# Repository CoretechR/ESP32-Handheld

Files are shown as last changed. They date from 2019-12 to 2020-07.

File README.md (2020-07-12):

# ESP32-Handheld

My image

Tested with Arduino for ESP32 Core 1.0.4

The lastes firmware needs the modified Adafruit SharpMem library. This library includes a hugely faster screen clearing function and hardware SPI.







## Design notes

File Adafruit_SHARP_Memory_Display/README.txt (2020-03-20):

This is an Arduino library for our Monochrome SHARP Memory Displays

  Pick one up today in the adafruit shop!
  ------> http://www.adafruit.com/products/1393

These displays use SPI to communicate, 3 pins are required to  
interface

To install this library, check out our detailed library install tutorial:
http://learn.adafruit.com/adafruit-all-about-arduino-libraries-install-use

Also requires the Adafruit GFX library, install the same way
https://github.com/adafruit/Adafruit-GFX-Library

Adafruit invests time and resources providing this open source code, 
please support Adafruit and open-source hardware by purchasing 
products from Adafruit!

Written by Limor Fried & Kevin Townsend  for Adafruit Industries.  
BSD license, check license.txt for more information
All text above, and the splash screen must be included in any redistribution

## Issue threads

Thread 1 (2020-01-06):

PJON compatible handheld device

gioblu, 2020-01-06:
Ciao Max, this is not really an issue.
I have really enjoyed your hackaday projects and this efficient handheld device.
Have you ever heard about PJON: https://github.com/gioblu/PJON ?

Would you be interested to work with us on something interesting?
This is my email gioscarab@gmail.com

Sorry for squatting the issues of this project to get in touch with you.

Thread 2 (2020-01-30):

Able to upload Bill Of Materials?

xlfe, 2020-01-30:
What a great project!

Any chance you would be able to upload a BOM please?

CoretechR, 2020-02-07:
Sorry for taking so long but here's the BOM:
[ESP32 Handheld BOM.txt](https://github.com/CoretechR/ESP32-Handheld/files/4172634/ESP32.Handheld.BOM.txt)

xlfe, 2020-02-08:
That's awesome - much appreciated @CoretechR

You wouldn't happen to have Digikey Part Numbers too?

CoretechR, 2020-02-08:
[Digikey Part Numbers.txt](https://github.com/CoretechR/ESP32-Handheld/files/4174643/Digikey.Part.Numbers.txt)
Please double check with the schematic. I already had some of the parts from other sources.

xlfe, 2020-02-09:
@CoretechR that's great - thank you.

Closed 2020-02-09.

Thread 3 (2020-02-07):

comments in code: save 80µA? and pinMode saves 10µA? how?

mahesh2000, 2020-02-07:
hi, the `Memo.ino` file states that two of the lines save 10µA and 80µA. could you point me towards the documentation that has more info about this? thanks!
the lines are:
```
pinMode(0, OUTPUT); // don't change, -10µA???
```

and

```
rtc_gpio_pulldown_dis(ulp_toggle_num); // disable VCOM pulldown (saves 80µA)
```

CoretechR, 2020-02-07:
These are values/improvements I made while monitoring the current with a multimeter.
The 80µA is probably caused by the VCOM being in a high state and the pulldown drawing current.
For the 10µA I have no idea, sorry. I was experimenting and this fix seemed to reduce current draw.

mahesh2000, 2020-02-07:
hi, what is VCOM? i didn't see that name on any of the pins. also, i got it down to 40uA in sleep mode; it's still 4x what ESP32 claims. but still pretty good. i removed several parts (see photos of surgery) the UART chip (scraped the pins off, it was too difficult to remove), "LDO" (if you can call it that), various resistors, transistors, a power inductor, pretty much everything. i left the tantalum capacitor in place as it was between Vcc and GND. and for the test code i used yours and some more:
```
/**
 * Reduce power consumption of the ESP32 during sleep
 *
 * Mahesh Viswanathan, Jan 2020, mahesh@leakspotter.com
 *
 */

// With just sleep code, consumption went down to 7.3mA, far too much.
// After removing the USB voltage regulator, a power inductor, UART. got it down to 40uA!

// probably don't need all these headers
#include "esp_sleep.h"
#include "driver/rtc_io.h"
#include "esp32/ulp.h"
#include "driver/adc.h"
#include "esp_wifi.h"
#include "esp_bt.h"
#include "WiFi.h"
#include <esp_wifi.h>
#include "esp32-hal-bt.h"

// from https://www.savjee.be/2019/12/esp32-tips-to-increase-battery-life/
void goToDeepSleep()
{
  Serial.println("Going to sleep...");
  WiFi.disconnect(true);
  WiFi.mode(WIFI_OFF);
  btStop();

  adc_power_off();
  //esp_wifi_stop();  // this crashes
  esp_bt_controller_disable();

  #define DEEP_SLEEP_TIME 15
  // Configure the timer to wake us up!
  esp_sleep_enable_timer_wakeup(DEEP_SLEEP_TIME * 60L * 1000000L);

  // Go to sleep! Zzzz
  esp_deep_sleep_start();
}
/**
 * Save power. from https://desire.giesecke.tk/index.php/2018/02/15/deep-sleep-needs-wifi-switched-off-for-low-current-consumption/
 * To achieve maximum power saving during deep sleep it is apparently necessary to switch off Bluetooth and WiFi before calling esp_deep_sleep_start();
 */
static void power_things_off() {
  // esp_wifi_stop(); // this causes endless rebooting. why?
  esp_sleep_pd_config(ESP_PD_DOMAIN_RTC_PERIPH, ESP_PD_OPTION_OFF);
  //WiFi.mode( WIFI_MODE_NULL );
  WiFi.mode(WIFI_OFF);
  btStop();
  adc_power_off();

  rtc_gpio_isolate((gpio_num_t) RTCIO_CHANNEL_0_GPIO_NUM);  //    36
  rtc_gpio_isolate((gpio_num_t) RTCIO_CHANNEL_1_GPIO_NUM); //    37
  rtc_gpio_isolate((gpio_num_t) RTCIO_CHANNEL_2_GPIO_NUM); //    38
  rtc_gpio_isolate((gpio_num_t) RTCIO_CHANNEL_3_GPIO_NUM); //    39
  rtc_gpio_isolate((gpio_num_t) RTCIO_CHANNEL_4_GPIO_NUM); //    34
  rtc_gpio_isolate((gpio_num_t) RTCIO_CHANNEL_5_GPIO_NUM); //    35
  rtc_gpio_isolate((gpio_num_t) RTCIO_CHANNEL_6_GPIO_NUM); //    25
  rtc_gpio_isolate((gpio_num_t) RTCIO_CHANNEL_7_GPIO_NUM); //    26
  rtc_gpio_isolate((gpio_num_t) RTCIO_CHANNEL_8_GPIO_NUM); //    33
  rtc_gpio_isolate((gpio_num_t) RTCIO_CHANNEL_9_GPIO_NUM); //    32
  rtc_gpio_isolate((gpio_num_t) RTCIO_CHANNEL_10_GPIO_NUM);  //   4
  rtc_gpio_isolate((gpio_num_t) RTCIO_CHANNEL_11_GPIO_NUM);  //   0
  rtc_gpio_isolate((gpio_num_t) RTCIO_CHANNEL_12_GPIO_NUM);  //   2
  rtc_gpio_isolate((gpio_num_t) RTCIO_CHANNEL_13_GPIO_NUM);  //   15
  rtc_gpio_isolate((gpio_num_t) RTCIO_CHANNEL_14_GPIO_NUM);  //   13
  rtc_gpio_isolate((gpio_num_t) RTCIO_CHANNEL_15_GPIO_NUM);  //   12
  rtc_gpio_isolate((gpio_num_t) RTCIO_CHANNEL_16_GPIO_NUM);  //   14
  rtc_gpio_isolate((gpio_num_t) RTCIO_CHANNEL_17_GPIO_NUM);  //   27

  //void rtc_gpio_force_hold_dis_all();
  rtc_gpio_force_hold_dis_all();

}

void print_wakeup_cause(esp_sleep_wakeup_cause_t cause) {
  Serial.print("Wakeup cause: ");
  if(cause == ESP_SLEEP_WAKEUP_UNDEFINED) Serial.println("ESP_SLEEP_WAKEUP_UNDEFINED"); //normal reset
  else if(cause == ESP_SLEEP_WAKEUP_ALL) Serial.println("ESP_SLEEP_WAKEUP_ALL");
  else if(cause == ESP_SLEEP_WAKEUP_EXT0) Serial.println("ESP_SLEEP_WAKEUP_EXT0");
  else if(cause == ESP_SLEEP_WAKEUP_EXT1) Serial.println("ESP_SLEEP_WAKEUP_EXT1"); //button A&B
  else if(cause == ESP_SLEEP_WAKEUP_TIMER) Serial.println("ESP_SLEEP_WAKEUP_TIMER"); //scheduled timer wakeup
  else if(cause == ESP_SLEEP_WAKEUP_TOUCHPAD) Serial.println("ESP_SLEEP_WAKEUP_TOUCHPAD");
  else if(cause == ESP_SLEEP_WAKEUP_ULP) Serial.println("ESP_SLEEP_WAKEUP_ULP");
  else if(cause == ESP_SLEEP_WAKEUP_GPIO) Serial.println("ESP_SLEEP_WAKEUP_GPIO");
  else if(cause == ESP_SLEEP_WAKEUP_UART) Serial.println("ESP_SLEEP_WAKEUP_UART");
}

/**
 * Entry point
 */
void setup(){
  delay(500); // "Unfortunately, the ESP32 software & hardware is not mature yet. There is a software or hardware bug that appears in both the ESP32 boards I tried when using the deep sleep mode. After a random number of wakes up, the ESP32 goes to sleep and it won’t wake up again. This bug can happen after a couple of wake ups or after 100. It is just random. One simple solution I discovered is to add a small delay of 500ms after waking up and before reading from the RTC memory. This way the project worked fine, but of course, the penalty we pay is reduced battery life, because the chip is in active mode for 500ms more in each wake-up. I think this bug will be resolved in the near future with a new software or hardware fix."
  // from https://www.hackster.io/nickthegreek82/esp32-deep-sleep-tutorial-4398a7

  esp_sleep_wakeup_cause_t cause = esp_sleep_get_wakeup_cause();
  pinMode(0, OUTPUT); // don't change, -10µA???

  Serial.begin(115200);
  delay(100);
  print_wakeup_cause(cause);

  power_things_off();
  goToDeepSleep();
}

void loop(void){
  Serial.println("You should never get here.");
}
```
Original, virgin board:
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

After ravaging -- look at all mess of parts desoldered and/or ripped out with needlenose pliers :-):
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

CoretechR, 2020-02-09:
From the code I can't see any obvious problems. With such a board it might be difficult to reliably measure the current. It would be best to measure directly on the VCC supply of the ESP32. Maybe you can cut a trace there and connect your multimeter. It also can help to set different "suspicious" pins to a low state, for example tx/rx or anything that's connected to other ICs. However 40µA is a pretty good result already.

mahesh2000, 2020-02-09:
yes, 40uA is good enough for me. that's why i'm not cutting out the rest. my multimeter is between my +3.3V and Vcc. the way i read the current is this:

```
3.3V _____/ _________ Vcc
       |          |
       |___ MM ___|

```

Close the switch. start the ESP32. put it into sleep mode. open the switch so the current now goes through the multimeter, which should be at the lowest setting. if you don't do that, the MM won't let enough current through and the ESP32 will not start properly. Once in sleep mode, it consumes very little current and this will give a good result. until the core wakes up again.

CoretechR, 2020-02-09:
Just a tip, you can also put a diode in parallel with the multimeter. The diode will let enough current through during startup and in sleep mode the diode will block nearly all current.
https://electronics.stackexchange.com/questions/340330/measure-wide-range-of-current-800-%c2%b5a-1-5-a/340353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
Oh, and VCOM is just part of the sharp display interface that I used.

mahesh2000, 2020-02-09:
does he mean i should use that circuit and put the MM across the 100 ohm resistor? it's not clear. it looks like an elegant solution.

CoretechR, 2020-02-09:
If you put your multimeter in current mode you only need the diode, the resistor is only a shunt for measuring the current.
```
3.3V ______▷| ________ Vcc Pin
       |          |
       |___ MM ___|

```

mahesh2000, 2020-02-09:
oh, nice!

Closed 2020-02-09.

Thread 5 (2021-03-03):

modify pins

Hausenbourne, 2021-03-03:
Hello friend, your project is really cool. I encountered some problems in the process of doing your project. Your SHARP_ VCOM pin is connected to IO2 pin of esp32, SHARP_ EXTMODE pin is connected to IO4 pin of esp32. Now I want to modify these two pins to connect to other IO ports of esp32. I have checked your code, but I can't find the relevant pin settings.

`#define SHARP_SCK  14`
`#define SHARP_MOSI 13`
`#define SHARP_SS   15`

CoretechR, 2021-03-04:
Hi,
the VCOM pin is toggled with the low power core of the ESP32. You need to look at this file to change the pin but not all pins on the ESP32 are available for it. About the EXTMODE I have no clue. Maybe I forgot to configure it and it works accidentally. It is pulled to ground by the default Arduino pin setting. And in standby there might be a weak pullup. I am not so sure anymore.

Closed 2021-12-29.

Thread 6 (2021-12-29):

Sharp Memory Display ESP32C3 RISC-V Compatibility

dgiampetruzzi, 2021-12-29:
Hi, thank you for this amazing project. I need an information. I would like to use the ESP32C3 to control the Sharp Memory Display. I know I could not use ULP to trigger VCOM (I would use an external RTC for this function). In general, is the library to drive this display compatible with the ESP32C3?
Thank you!

CoretechR, 2021-12-29:
Hi, the underlying library is Adafruit GFX (https://github.com/adafruit/Adafruit-GFX-Library). I have not used a ESP32C3 before so I can't guarantee that it works. But it seems likely as the only necessary peripheral is SPI. The only way to find out is to try it.  :)
Using an RTC for the 1Hz signal is a good idea. Does the ESP32C3 not have a ULP at all?

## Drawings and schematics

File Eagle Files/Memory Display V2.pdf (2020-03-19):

# ESP32 Wroom

FTDI Adapter | LiPo Charger

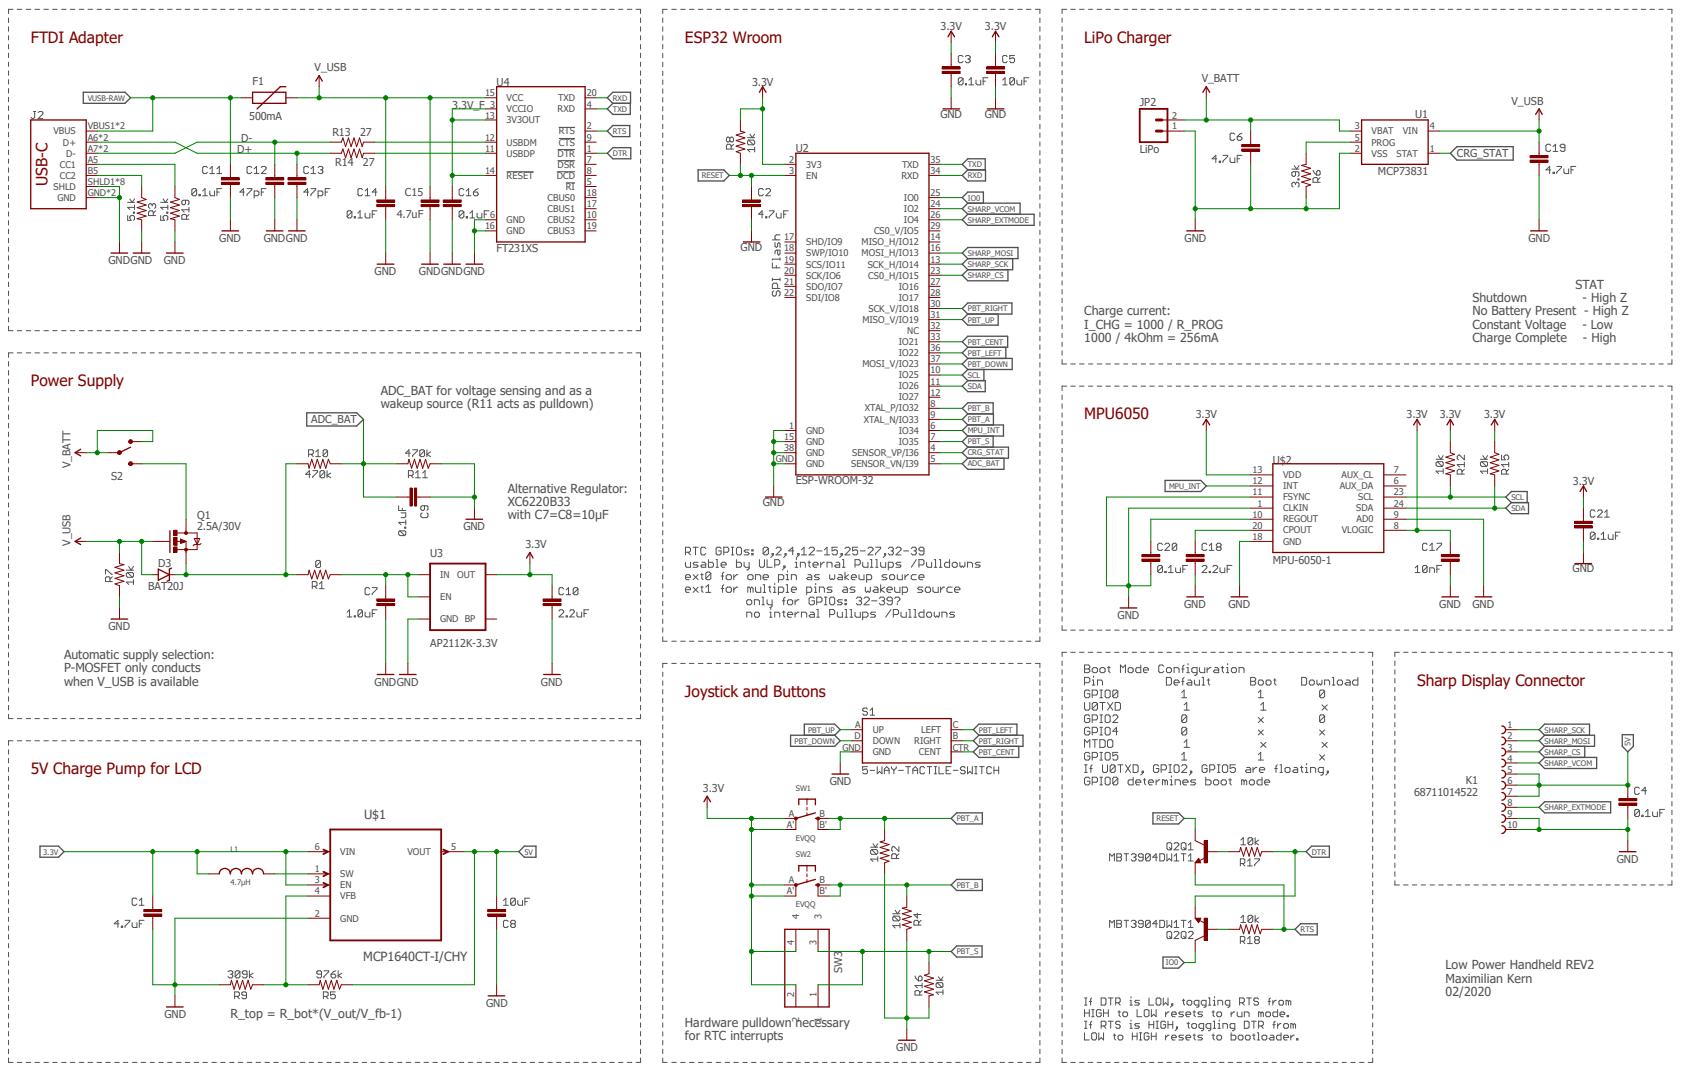
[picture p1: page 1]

No Battery Present - High Z
Constant Voltage - Low
Charge Complete - High

ADC_BAT for voltage sensing and as a
wakeup source (R11 acts as pulldown)

5V Charge Pump for LCD

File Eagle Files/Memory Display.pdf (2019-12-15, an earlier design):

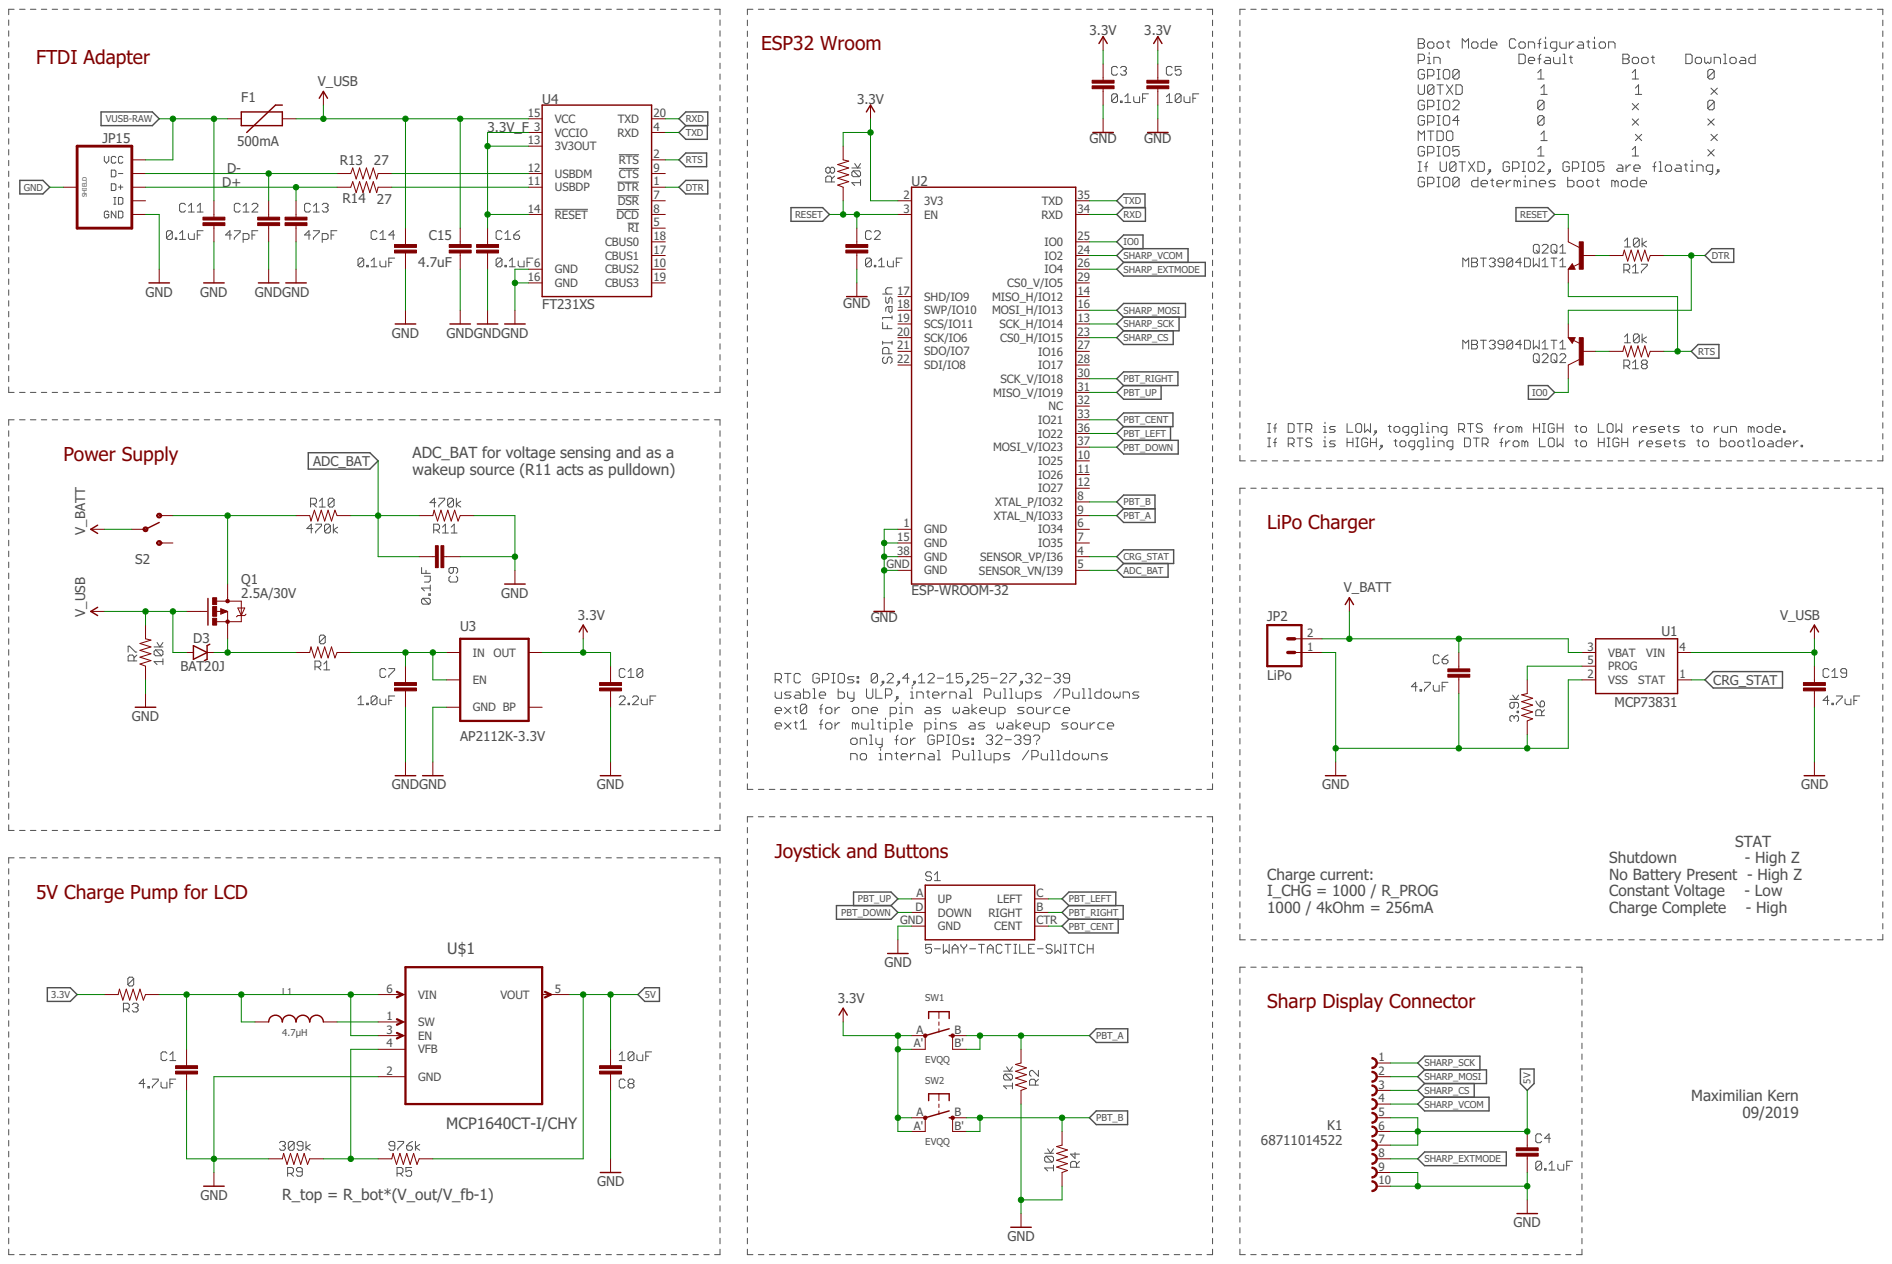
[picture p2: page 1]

ADC_BAT for voltage sensing and as a wakeup source (R11 acts as pulldown)

No Battery Present - High Z

5V Charge Pump for LCD

PBT_UP | PBT_LEFT
PBT_DOWN GND | PBT_RIGHT

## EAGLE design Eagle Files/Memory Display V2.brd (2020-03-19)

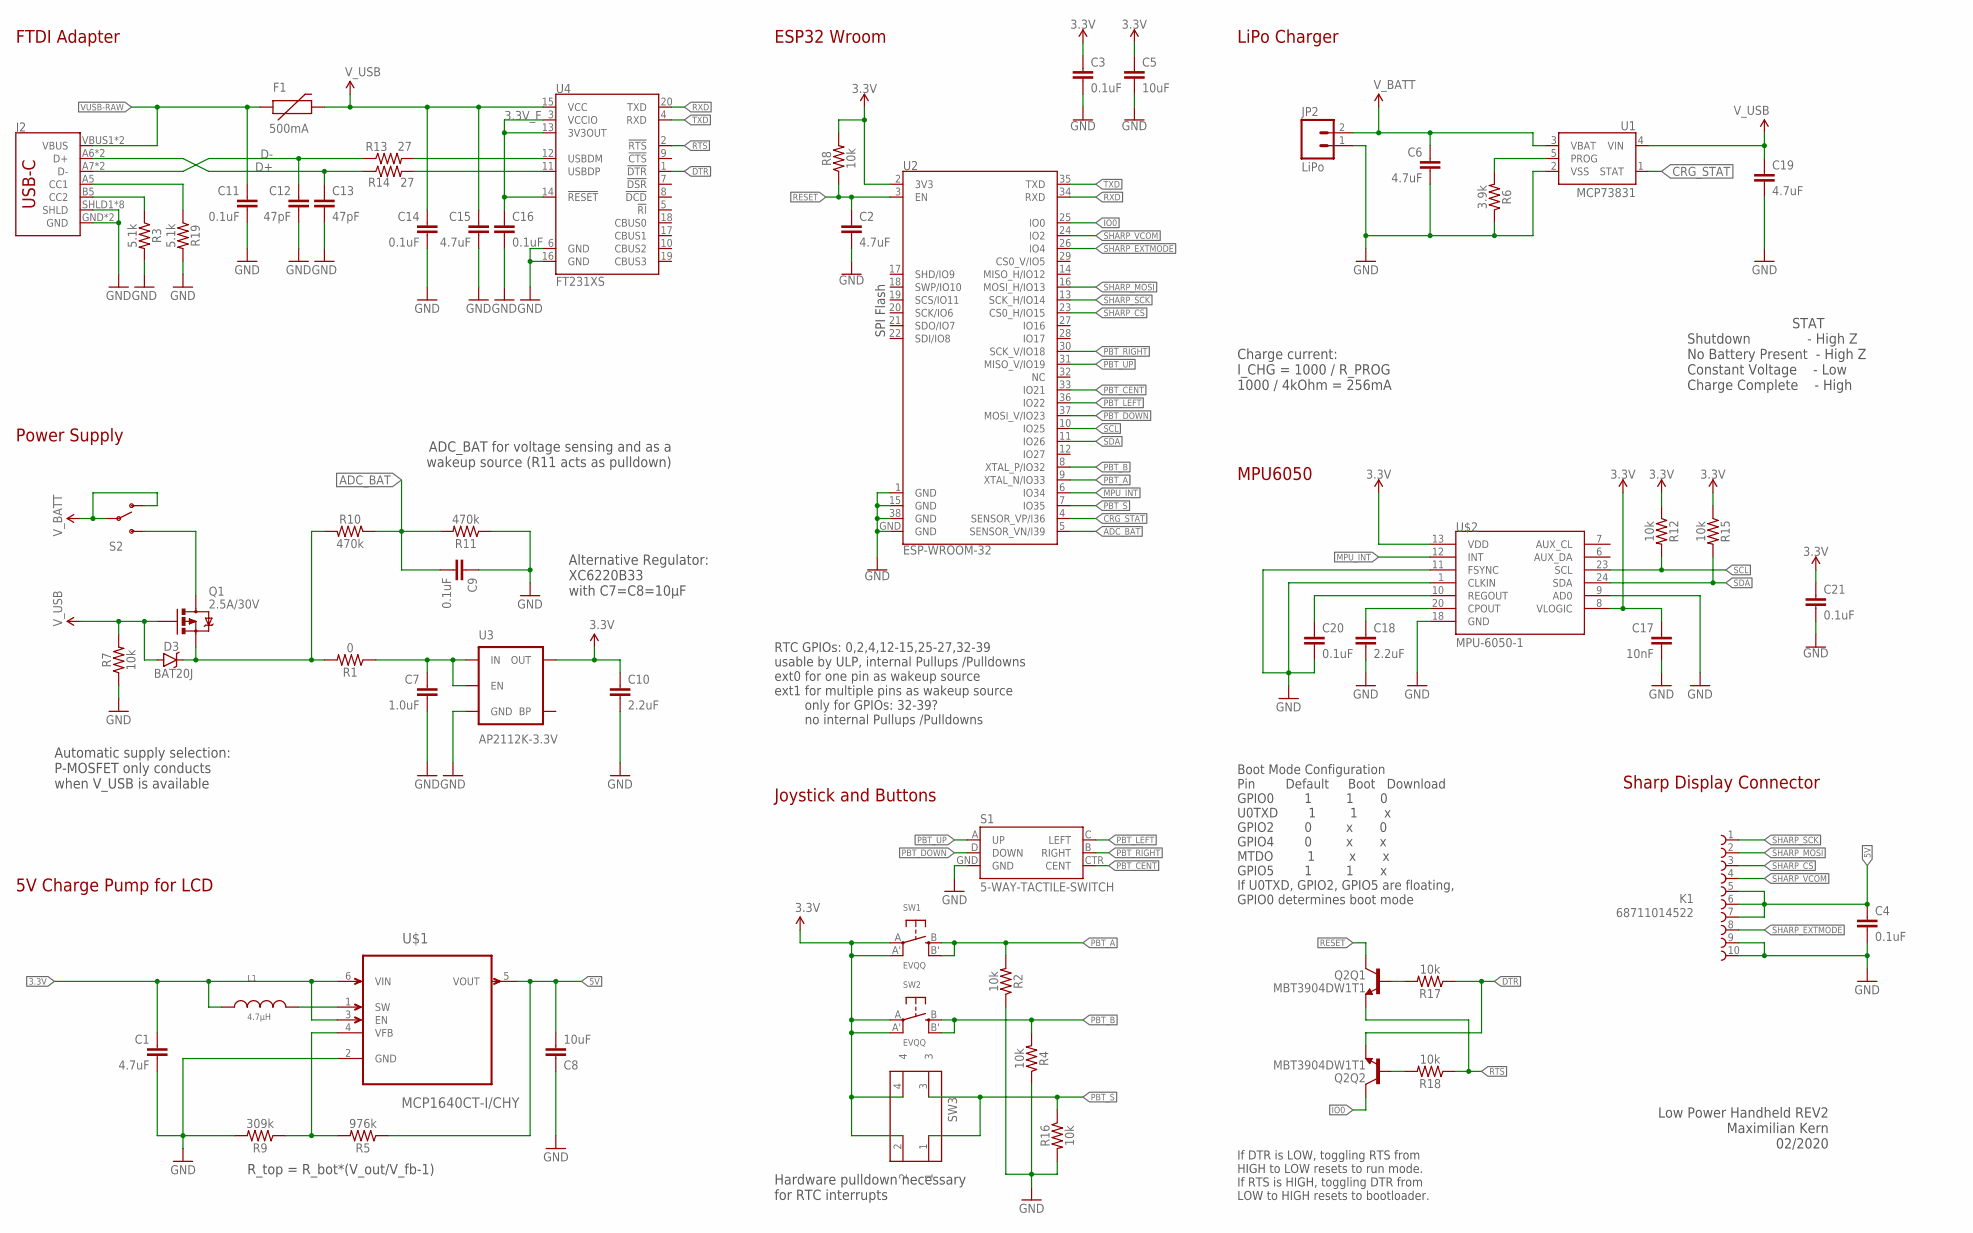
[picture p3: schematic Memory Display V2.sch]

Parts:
C1, C2, C6, C19: 4.7uF; 0603
C3, C4, C9, C11, C14, C16, C20, C21: 0.1uF; 0603
C5, C8: 10uF; 0603
C7: 1.0uF; 0805
C10, C18: 2.2uF; 0805
C12, C13: 47pF; 0603
C15: 4.7uF; 0603-CAP
C17: 10nF; 0603
D3: BAT20J; SOD-323
F1: 500mA; PTC-1206
J2: USB_C16PIN; USB-C-16P
JP2: LiPo; JST-2-PTH
K1: 68711014522
L1: 4.7µH; WE-TPC_2811/2813_OLD
Q1: 2.5A/30V; SOT23-3
Q2: MBT3904DW1T1; SC70-6
R1: 0; 0603
R2, R4, R7, R8, R12, R15, R16, R17, R18: 10k; 0603
R3, R19: 5.1k; 0603
R5: 976k; 0603
R6: 3.9k; 0603
R9: 309k; 0603
R10, R11: 470k; 0603
R13, R14: 27; 0603
S1: 5-WAY-TACTILE-SWITCH; JOYSTICK_MINI
S2: SWITCH-SPDT-SMD-A; SWITCH-SPST-SMD-A
SW1, SW2: EVQQ; EVQ-Q2_SMALLER
SW3: 434331045822
U1: MCP73831; SOT23-5
U2: ESP-WROOM-32
U3: AP2112K-3.3V; SOT23-5
U4: FT231XS; SSOP20_L
U$1: MCP1640CT-I/CHY; SOT95P270X145-6N
U$2: MPU-6050-1; QFN-24-4MM2

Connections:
3.3V: C1.1, C3.1, C5.1, C10.1, C17.1, C21.1, L1.1, R8.2, R12.1, R15.1, SW1.A, SW1.A' (P1), SW2.A, SW2.A' (P1), SW3.2, SW3.4, U2.2 (3V3), U3.5 (OUT), U$1.3 (EN), U$1.6 (VIN), U$2.8 (VLOGIC), U$2.13 (VDD)
3.3V_F: C16.1, U4.3 (VCCIO), U4.13 (3V3OUT), U4.14 (!RESET)
5V: C4.1, C8.2, K1.5, K1.6, K1.7, R5.1, U$1.5 (VOUT)
ADC_BAT: C9.2, R10.1, R11.2, U2.5 (SENSOR_VN/I39)
B_VFB: R5.2, R9.1, U$1.4 (VFB)
CRG_STAT: U1.1 (STAT), U2.4 (SENSOR_VP/I36)
D+: C13.1, J2.A6 (D+), J2.B6 (D+), R14.1
D-: C12.1, J2.A7 (D-), J2.B7 (D-), R13.1
DTR: Q2.1 (E), R17.1, U4.1 (!DTR)
GND: C1.2, C2.2, C3.2, C4.2, C5.2, C6.2, C7.2, C8.1, C9.1, C10.2, C11.2, C12.2, C13.2, C14.2, C15.2, C16.2, C17.2, C18.2, C19.2, C20.2, C21.2, J2.GND, J2.GND2 (GND), J2.SHLD1 (SHLD), J2.SHLD2 (SHLD), J2.SHLD3 (SHLD), J2.SHLD4 (SHLD), J2.SHLD5 (SHLD), J2.SHLD6 (SHLD), J2.SHLD7 (SHLD), J2.SHLD8 (SHLD), JP2.1, K1.9, K1.10, R2.1, R3.2, R4.1, R6.1, R7.1, R9.2, R11.1, R16.2, R19.2, S1.GND, U1.2 (VSS), U2.1 (GND), U2.15 (GND), U2.38 (GND), U2.GND, U3.2 (GND), U4.6 (GND), U4.16 (GND), U$1.2 (GND), U$2.1 (CLKIN), U$2.9 (AD0), U$2.11 (FSYNC), U$2.18 (GND)
IO0: Q2.6 (C), U2.25 (IO0)
MPU_INT: U2.6 (IO34), U$2.12 (INT)
unnamed: L1.2, U$1.1 (SW)
unnamed: C7.1, R1.1, U3.1 (IN), U3.3 (EN)
unnamed: Q1.3 (D), S2.3 (S)
unnamed: D3.C, Q1.2 (S), R1.2, R10.2
unnamed: R13.2, U4.12 (USBDM)
unnamed: R14.2, U4.11 (USBDP)
unnamed: J2.A5 (CC1), R19.1
unnamed: Q2.5 (B), R17.2
unnamed: J2.B5 (CC2), R3.1
unnamed: Q2.2 (B), R18.2
unnamed: R6.2, U1.5 (PROG)
unnamed: C18.1, U$2.20 (CPOUT)
unnamed: C20.1, U$2.10 (REGOUT)
PBT_A: R2.2, SW1.B (S), SW1.B' (S1), U2.9 (XTAL_N/IO33)
PBT_B: R4.2, SW2.B (S), SW2.B' (S1), U2.8 (XTAL_P/IO32)
PBT_CENT: S1.CTR (CENT), U2.33 (IO21)
PBT_DOWN: S1.D (DOWN), U2.37 (MOSI_V/IO23)
PBT_LEFT: S1.C (LEFT), U2.36 (IO22)
PBT_RIGHT: S1.B (RIGHT), U2.30 (SCK_V/IO18)
PBT_S: R16.1, SW3.1, SW3.3, U2.7 (IO35)
PBT_UP: S1.A (UP), U2.31 (MISO_V/IO19)
RESET: C2.1, Q2.3 (C), R8.1, U2.3 (EN)
RTS: Q2.4 (E), R18.1, U4.2 (!RTS)
RXD: U2.34 (RXD), U4.20 (TXD)
SCL: R12.2, U2.10 (IO25), U$2.23 (SCL)
SDA: R15.2, U2.11 (IO26), U$2.24 (SDA)
SHARP_CS: K1.3, U2.23 (CS0_H/IO15)
SHARP_EXTMODE: K1.8, U2.26 (IO4)
SHARP_MOSI: K1.2, U2.16 (MOSI_H/IO13)
SHARP_SCK: K1.1, U2.13 (SCK_H/IO14)
SHARP_VCOM: K1.4, U2.24 (IO2)
TXD: U2.35 (TXD), U4.4 (RXD)
VUSB-RAW: C11.1, F1.1, J2.VBUS1 (VBUS), J2.VBUS2 (VBUS)
V_BATT: C6.1, JP2.2, S2.1 (O), S2.2, U1.3 (VBAT)
V_USB: C14.1, C15.1, C19.1, D3.A, F1.2, Q1.1 (G), R7.2, U1.4 (VIN), U4.15 (VCC)

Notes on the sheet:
ESP32 Wroom
Boot Mode Configuration Pin Default Boot Download GPIO0 1 1 0 U0TXD 1 1 x GPIO2 0 x 0 GPIO4 0 x x MTDO 1 x x GPIO5 1 1 x If U0TXD, GPIO2, GPIO5 are floating, GPIO0 determines boot mode
If DTR is LOW, toggling RTS from HIGH to LOW resets to run mode. If RTS is HIGH, toggling DTR from LOW to HIGH resets to bootloader.
Charge current: I_CHG = 1000 / R_PROG 1000 / 4kOhm = 256mA
Power Supply
FTDI Adapter
LiPo Charger
Joystick and Buttons
5V Charge Pump for LCD
RTC GPIOs: 0,2,4,12-15,25-27,32-39 usable by ULP, internal Pullups /Pulldowns ext0 for one pin as wakeup source ext1 for multiple pins as wakeup source only for GPIOs: 32-39? no internal Pullups /Pulldowns
SPI Flash
Low Power Handheld REV2 Maximilian Kern 02/2020
STAT Shutdown - High Z No Battery Present - High Z Constant Voltage - Low Charge Complete - High
ADC_BAT for voltage sensing and as a wakeup source (R11 acts as pulldown)
R_top = R_bot*(V_out/V_fb-1)
Sharp Display Connector
MPU6050
Alternative Regulator: XC6220B33 with C7=C8=10µF
Automatic supply selection: P-MOSFET only conducts when V_USB is available
Hardware pulldown necessary for RTC interrupts

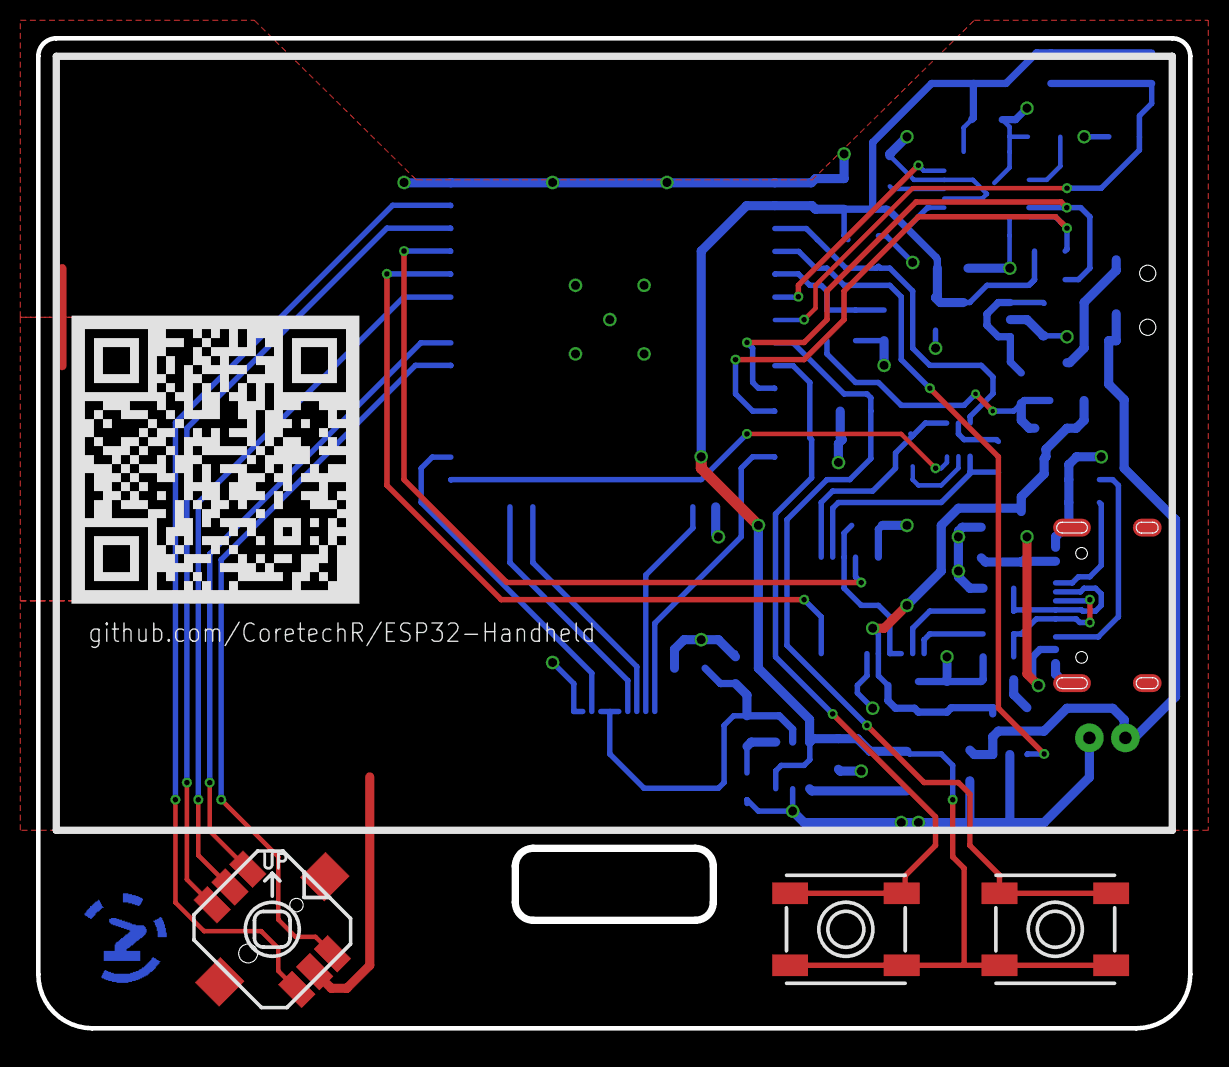
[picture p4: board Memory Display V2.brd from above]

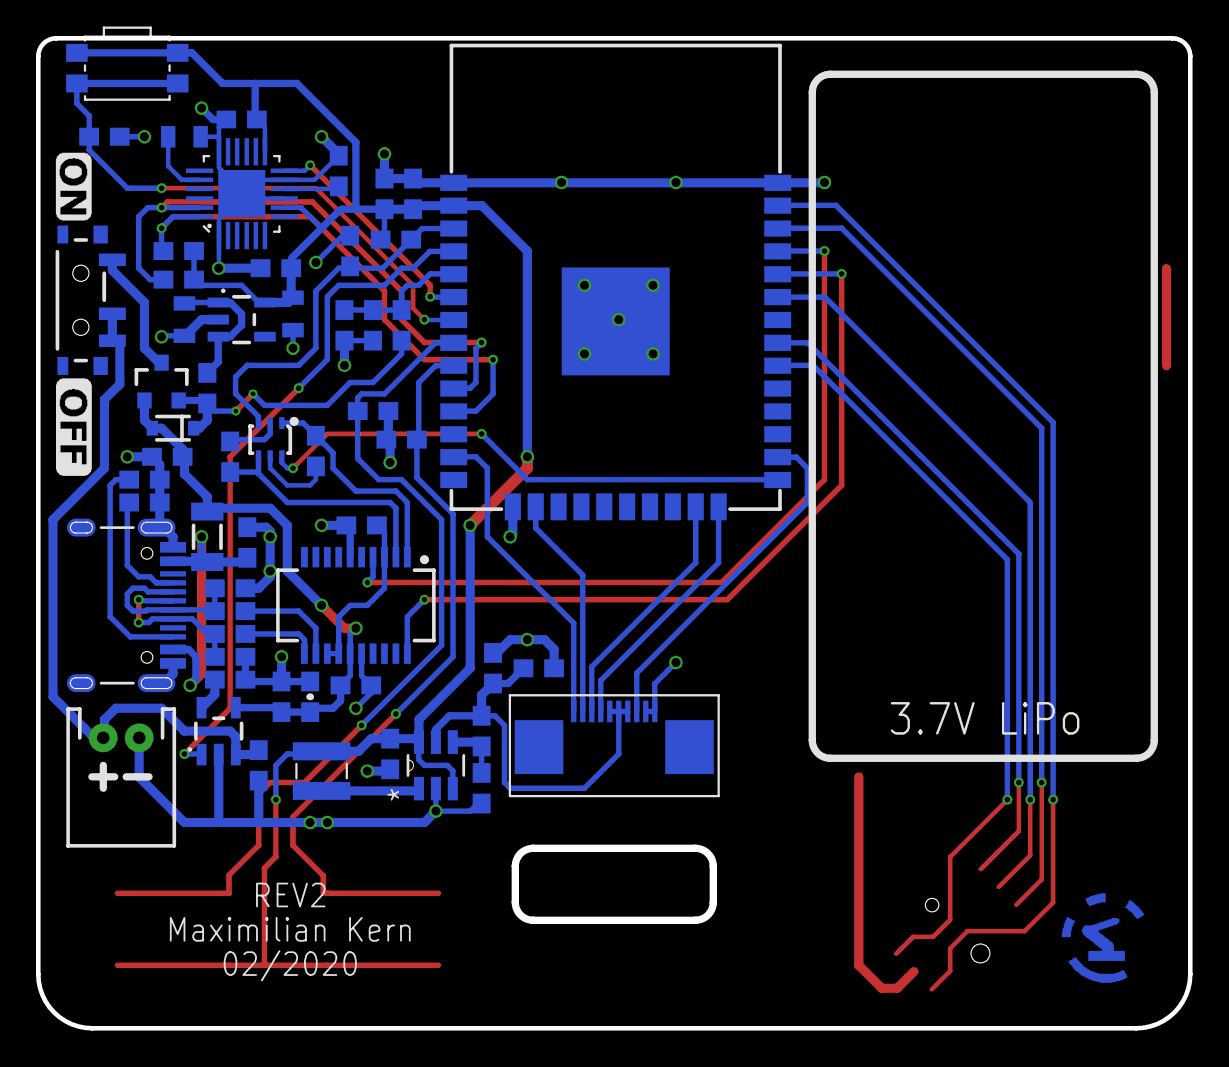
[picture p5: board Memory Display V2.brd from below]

Board: 2 copper layers, 64.0 x 55.0 mm, 59 parts (56 on the bottom side), 47 nets.

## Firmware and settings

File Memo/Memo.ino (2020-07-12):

// Tested with ESP32 Core V1.0.4
//#define ANCS //uncomment to enable ANCS messages
#include <Adafruit_GFX.h>
#include <Adafruit_SharpMem.h>
#include <Fonts/FreeSansBold9pt7b.h>
#include <Fonts/FreeSans9pt7b.h>

#include <Button.h> // https://github.com/JChristensen/Button

#include "esp_sleep.h"
#include "driver/rtc_io.h"
#include "esp32/ulp.h"
#include "bmp.h"

#include "ulp_main.h"
#include "ulptool.h"

#include <WiFi.h>
#include <HTTPClient.h>
#include <NTPClient.h>

#include "I2Cdev.h"
#include "MPU6050.h"
#include "Wire.h"
MPU6050 mpu;

#ifdef ANCS
  #include "esp32notifications.h" // https://www.github.com/Smartphone-Companions/ESP32-ANCS-Notifications.git
  BLENotifications notifications;
  uint32_t incomingCallNotificationUUID;
  boolean ancsDisconnectFlag = false;
  String latestNotificationTitle;
  String latestNotificationMessage;
  unsigned long notificatonCounter = 0;
#endif
 
char* ssid = "SSIDA";
char* password = "PASSWORDA";

char* ssidB = "SSIDB";
char* passwordB = "PASSWORDB";

WiFiUDP ntpUDP;
NTPClient timeClient(ntpUDP);

#define BLACK 0
#define WHITE 1

#define WIDTH 400
#define HEIGHT 240

#define SHARP_SCK  14
#define SHARP_MOSI 13
#define SHARP_SS   15

#define I2C_SDA 26
#define I2C_SCL 25
#define INTP 34

#define ADC_BAT 39
#define CRG_STAT 36

#define ABUT 33
#define BBUT 32
#define UBUT 19
#define DBUT 23
#define LBUT 22
#define RBUT 18
#define CBUT 21
#define SBUT 35

//#define SKIPBOOTSCREEN

//Pushbuttons connected to GPIO32 & GPIO33 for wakeup
#define BUTTON_PIN_BITMASK 0x300000000
extern const uint8_t ulp_main_bin_start[] asm("_binary_ulp_main_bin_start");
extern const uint8_t ulp_main_bin_end[]   asm("_binary_ulp_main_bin_end");
gpio_num_t ulp_toggle_num = GPIO_NUM_2;

Button buttonA(ABUT, false, false, 5); //pin, pullup, invert, debounce
Button buttonB(BBUT, false, false, 5);
Button buttonUp(UBUT, true, true, 5); // turn on pullups for joystick only
Button buttonDown(DBUT, true, true, 5);
Button buttonLeft(LBUT, true, true, 5);
Button buttonRight(RBUT, true, true, 5);
Button buttonC(CBUT, true, true, 5);
Button buttonShoulder(SBUT, false, false, 5);

TaskHandle_t Task1;
TaskHandle_t Task2;

Adafruit_SharpMem display(SHARP_SCK, SHARP_MOSI, SHARP_SS, 400, 240);

int currentPage = 0; // main menu

unsigned long fpsCounter = 0;
float fps = 0;

float battVoltage;
float chargeState;
boolean USBConnected = true;
boolean BLEConnected = false;
boolean Charging = false;
boolean batteryConnected = true;

struct tm now;
RTC_DATA_ATTR int syncCounter = 0; //count wakeups for time sync (RTC memory is not erased during sleep)

float mouseX, mouseY;

int16_t gx, gy, gz;
float sensX = 0.0022;
float sensY = 0.0018;

static void init_ulp_program() 
{
  esp_err_t err = ulptool_load_binary(0, ulp_main_bin_start, (ulp_main_bin_end - ulp_main_bin_start) / sizeof(uint32_t));
  ESP_ERROR_CHECK(err);

  rtc_gpio_init(ulp_toggle_num);
  rtc_gpio_pulldown_dis(ulp_toggle_num); // disable VCOM pulldown (saves 80µA)
  rtc_gpio_set_direction(ulp_toggle_num, RTC_GPIO_MODE_OUTPUT_ONLY);

  /* Set ULP wake up period to 500ms */
  ulp_set_wakeup_period(0, 500 * 1000);
}

void enterSleep(){
  //Serial.printf("Entering deep sleep\n\n");
  /* Turn off wireless features */ //needs to be tested but should be OK!
  WiFi.disconnect(true);
  WiFi.mode(WIFI_OFF);
  btStop();
  /* Put MPU6050 into sleep mode */
  mpu.setSleepEnabled(true);
  /* Start the ULP program */
  ESP_ERROR_CHECK( ulp_run((&ulp_entry - RTC_SLOW_MEM) / sizeof(uint32_t)));
  ESP_ERROR_CHECK( esp_sleep_enable_ulp_wakeup() );
  //Configure GPIO32 & GPIO33 as ext1 wake up source for HIGH logic level
  esp_sleep_enable_ext1_wakeup(BUTTON_PIN_BITMASK,ESP_EXT1_WAKEUP_ANY_HIGH);
  //wake up at full minute
  esp_sleep_enable_timer_wakeup((60-now.tm_sec) * 1000000);
  //Go to sleep now
  esp_deep_sleep_start();
}

void setup(void){

  esp_sleep_wakeup_cause_t cause = esp_sleep_get_wakeup_cause();
  if (cause != ESP_SLEEP_WAKEUP_ULP) {
    init_ulp_program();
  }
  if(cause == ESP_SLEEP_WAKEUP_TIMER){
    if(syncCounter++ >= 360){ //sync with ntp server every 6h
      syncRTC();
      syncCounter = 0;
    }
    display.begin();
    display.clearDisplay();
    display.setRotation(0);
    getLocalTime(&now,0);
    drawClock();
    enterSleep();
  }
  pinMode(0, OUTPUT); // don't change, -10µA???

  display.begin();
  display.clearDisplay();
  display.setRotation(0); //Tetris?

  Serial.begin(115200);
  Serial.print("Wakeup cause: ");
  if(cause == ESP_SLEEP_WAKEUP_UNDEFINED) Serial.println("ESP_SLEEP_WAKEUP_UNDEFINED"); //normal reset
  else if(cause == ESP_SLEEP_WAKEUP_ALL) Serial.println("ESP_SLEEP_WAKEUP_ALL");
  else if(cause == ESP_SLEEP_WAKEUP_EXT0) Serial.println("ESP_SLEEP_WAKEUP_EXT0");
  else if(cause == ESP_SLEEP_WAKEUP_EXT1) Serial.println("ESP_SLEEP_WAKEUP_EXT1"); //button A&B
  else if(cause == ESP_SLEEP_WAKEUP_TIMER) Serial.println("ESP_SLEEP_WAKEUP_TIMER"); //scheduled timer wakeup
  else if(cause == ESP_SLEEP_WAKEUP_TOUCHPAD) Serial.println("ESP_SLEEP_WAKEUP_TOUCHPAD");
  else if(cause == ESP_SLEEP_WAKEUP_ULP) Serial.println("ESP_SLEEP_WAKEUP_ULP");
  else if(cause == ESP_SLEEP_WAKEUP_GPIO) Serial.println("ESP_SLEEP_WAKEUP_GPIO");
  else if(cause == ESP_SLEEP_WAKEUP_UART) Serial.println("ESP_SLEEP_WAKEUP_UART");


  pinMode(ABUT, INPUT);
  pinMode(BBUT, INPUT);
  pinMode(UBUT, INPUT_PULLUP);
  pinMode(DBUT, INPUT_PULLUP);
  pinMode(LBUT, INPUT_PULLUP);
  pinMode(RBUT, INPUT_PULLUP);
  pinMode(CBUT, INPUT_PULLUP);
  pinMode(SBUT, INPUT_PULLUP);

  pinMode(CRG_STAT, INPUT);
  pinMode(ADC_BAT, INPUT);
  pinMode(INTP, INPUT_PULLUP);
  adcAttachPin(CRG_STAT);
  adcAttachPin(ADC_BAT);
  analogReadResolution(12);
  analogSetWidth(12);
  analogSetAttenuation(ADC_11db);

  
  Wire.begin(I2C_SDA, I2C_SCL, 400000);
  mpu.initialize();
  mpu.setXAccelOffset(-1839);
  mpu.setYAccelOffset(893);
  mpu.setZAccelOffset(4861);
  mpu.setXGyroOffset(87);
  mpu.setYGyroOffset(22);
  mpu.setZGyroOffset(-130);
  
  //create a task that will be executed in the Task1code() function, with priority 1 and executed on core 0
  xTaskCreatePinnedToCore(
                    Task1code,   /* Task function. */
                    "Task1",     /* name of task. */
                    10000,       /* Stack size of task */
                    NULL,        /* parameter of the task */
                    1,           /* priority of the task */
                    &Task1,      /* Task handle to keep track of created task */
                    0);          /* pin task to core 0 */     

  #ifdef ANCS
    notifications.begin("ESP32 Memo"); // Start ANCS 
    notifications.setConnectionStateChangedCallback(onBLEStateChanged);
    notifications.setNotificationCallback(onNotificationArrived);
    notifications.setRemovedCallback(onNotificationRemoved);
  #endif
                           
  if(cause == ESP_SLEEP_WAKEUP_UNDEFINED){ //run on reset only
    #if !defined SKIPBOOTSCREEN
      display.fillScreen(BLACK);
      display.setTextSize(2);
      display.setTextColor(WHITE);
      display.setCursor(0, 20);
      display.println("Memory Display OS Version 0.07");
      display.refresh();
      display.println("Copyright(C) 2019-2020 CoreTech");
      display.refresh();
      display.printf("CPU: Xtensa LX6 2 CPU %dMHz\n\n", getCpuFrequencyMhz());
      display.refresh();

      if (WifiConnect(5) == false){ // switch to backup wifi
        ssid = ssidB;
        password = passwordB;
      }
      
      display.println("Fetching time from NTP server...");
      if(syncRTC()) display.println("Time synced");
      else display.println("Time sync failed");
      display.refresh();
      delay(500);
    #endif
  }

  setMenuPos();
  
}

void Task1code( void * pvParameters ){
  for(;;){
    adcAttachPin(CRG_STAT);
    adcAttachPin(ADC_BAT);
    analogReadResolution(12);
    analogSetWidth(12);
    analogSetAttenuation(ADC_11db);
  
    battVoltage = analogRead(ADC_BAT)*6.6/4096.0*1.1;
    if(battVoltage < 3.6 && battVoltage > 2){ //force standby when battery is critical
      display.fillScreen(WHITE);
      display.setTextSize(3);
      display.setTextColor(BLACK);
      display.setCursor(0, 26);
      display.println("  Battery Critical");
      display.println("  Please turn off");
      display.println("  and recharge");
      display.refresh();
      /* Put MPU6050 into sleep mode */
      WiFi.disconnect(true);
      WiFi.mode(WIFI_OFF);
      btStop();
      mpu.setSleepEnabled(true);
      esp_deep_sleep_start();
    }
    //TODO: measure V_USB in next hardware revision!
    if(battVoltage > 4.21){
      Charging = true;
      USBConnected = true;
      batteryConnected = true;
    }
    else if(battVoltage < 1){
      Charging = false;
      USBConnected = true;
      batteryConnected = false;
    }
    else{
      Charging = false;
      USBConnected = false;
      batteryConnected = true;
    }
    #ifdef ANCS
    // Restart BLE Advertising to prevent reconnect issue
    if(ancsDisconnectFlag) { 
      delay(100);
      notifications.startAdvertising();
      ancsDisconnectFlag = false;
    }
    #endif
    getLocalTime(&now,0);
    delay(500); //core 0 needs free time for background tasks
  }
}

void loop(void){
  fps = 1000/float(millis()-fpsCounter);
  fpsCounter = millis();

  
  //Serial.print(fps);
  //Serial.println("fps");

  if(currentPage == 1) drawPaint();
  //else if(currentPage == 2) drawSettings();
  else if(currentPage == 3) drawCalc();
  else if(currentPage == 4) drawNews();
  else if(currentPage == 5) drawClockApp();
  else if(currentPage == 6) drawLunar();
  else if(currentPage == 7) drawKeyboardDemo();
  //else if(currentPage == 8) drawOpac();
  else if(currentPage == 9) drawSpiritLevel();
  else if(currentPage == 10) drawHackaday();
  else drawMainMenu();
}

///

void drawTaskBar(){
  display.fillRect(0, 0, WIDTH, 16, BLACK);
  //time
  display.setFont();
  display.setTextSize(2);
  display.setTextColor(WHITE);
  //clock
  display.setCursor(WIDTH/2-26,0);
  display.printf("%02d:%02d", now.tm_hour, now.tm_min);
  //battery
  //display.printf("   %d", analogRead(ADC_BAT));
  display.setCursor(10,0);  
  //display.printf(" %.2fV", battVoltage);
  display.drawRect(WIDTH-30, 3, 19, 10, WHITE);
  display.fillRect(WIDTH-11, 5, 2, 6, WHITE);
  if(batteryConnected){
    if(battVoltage > 3.7) display.fillRect(WIDTH-28, 5, 3, 6, WHITE);
    if(battVoltage > 3.8) display.fillRect(WIDTH-24, 5, 3, 6, WHITE);
    if(battVoltage > 3.9) display.fillRect(WIDTH-20, 5, 3, 6, WHITE);
    if(battVoltage > 4.1) display.fillRect(WIDTH-16, 5, 3, 6, WHITE);
  }
  //USB
  if(USBConnected){
    display.fillRect(WIDTH-45, 5, 9, 5, WHITE);
    display.fillRect(WIDTH-44, 2, 2, 4, WHITE);
    display.fillRect(WIDTH-39, 2, 2, 4, WHITE);
    display.fillRect(WIDTH-42, 10, 3, 4, WHITE);
  }
  if(BLEConnected){
    display.drawBitmap(WIDTH-57, 2, bluetooth_bmp, 6, 12, WHITE);
  }
  #ifdef ANCS
    if(notificatonCounter > millis()){
      display.fillRect(0, 16, WIDTH, 50, BLACK);
      display.fillRoundRect(5, 16, WIDTH-(5*2), 50-5, 6, WHITE);
      display.setCursor(8, 28);
      display.setTextSize(1);
      display.setTextColor(BLACK);
  
      display.setTextWrap(false);
      display.setFont(&FreeSansBold9pt7b);
      display.print(latestNotificationTitle.substring(0, 42));
      
      display.setCursor(8, 54);
      display.setFont(&FreeSans9pt7b);
      display.print(latestNotificationMessage.substring(0, 42));
      if(latestNotificationMessage.length() >= 38) display.print("...");
      display.setTextWrap(true);
    
      display.setFont();
    }
  #endif
    
}

void grayRect(int x, int y, int w, int h) {
  boolean toggle = true;
  for (int i = x; i < x+w; i++) {
    for (int k = y; k < y+h; k++) {
      if (toggle) display.drawPixel(i, k+i%2, BLACK);
      toggle = !toggle;
    }
  }
}

boolean syncRTC(){
  if(WifiConnect(5)){
    timeClient.begin();
    timeClient.setTimeOffset(7200); //+2hr for DST
    timeClient.update();
    timeval epoch = {timeClient.getEpochTime(), 0};
    const timeval *tv = &epoch;
    timezone utc = {0,0};
    const timezone *tz = &utc;
    settimeofday(tv, tz);
    WiFi.disconnect();
    WiFi.mode(WIFI_OFF);
    return true;
  }
  else return false;
}

boolean WifiConnect(unsigned int timeout){
  WiFi.begin(ssid, password);
  while (WiFi.status() != WL_CONNECTED) {
      delay(500);
      timeout--;
      if(timeout == 0) break;
  }
  if(WiFi.status() == WL_CONNECTED) return true;
  else return false;
}

void drawClock(){
  display.fillScreen(BLACK);
  display.setTextSize(12);
  display.setTextColor(WHITE);
  display.setCursor(25, 60);
  display.printf("%02d:%02d", now.tm_hour, now.tm_min);
  display.setTextSize(4);
  display.setCursor(25, 160);
  display.printf("%d.%d.%d", now.tm_mday, now.tm_mon+1, now.tm_year+1900);
  display.refresh();
}

#ifdef ANCS
  void onNotificationRemoved(const ArduinoNotification * notification, const Notification * rawNotificationData) {
       display.printf("Removed notification: %s\n%s\n%s\n", notification->title, notification->message, notification->type);
  }
  
  void onNotificationArrived(const ArduinoNotification * notification, const Notification * rawNotificationData) {
      latestNotificationTitle = notification->title;
      latestNotificationMessage = notification->message;    
      display.printf("Got notification: %s\n%s\n%s\n", notification->title, notification->message, notification->type);
      Serial.println(notifications.getNotificationCategoryDescription(notification->category));  // ie "social media"
      Serial.println(notification->categoryCount); // How may other notifications are there from this app (ie badge number)
      notificatonCounter = millis() + 3000;
  }
  
  void onBLEStateChanged(BLENotifications::State state) {
    switch(state) {
        case BLENotifications::StateConnected:
            Serial.println("StateConnected - connected to a phone or tablet");
            BLEConnected = true;
            break;
  
        case BLENotifications::StateDisconnected:
            Serial.println("StateDisconnected - disconnected from a phone or tablet"); 
            ancsDisconnectFlag = true;
            BLEConnected = false;
            break; 
    }
  }
#endif

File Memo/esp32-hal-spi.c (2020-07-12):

// Copyright 2015-2016 Espressif Systems (Shanghai) PTE LTD
//
// Licensed under the Apache License, Version 2.0 (the "License");
// you may not use this file except in compliance with the License.
// You may obtain a copy of the License at

//     http://www.apache.org/licenses/LICENSE-2.0
//
// Unless required by applicable law or agreed to in writing, software
// distributed under the License is distributed on an "AS IS" BASIS,
// WITHOUT WARRANTIES OR CONDITIONS OF ANY KIND, either express or implied.
// See the License for the specific language governing permissions and
// limitations under the License.

#include "esp32-hal-spi.h"
#include "esp32-hal.h"
#include "freertos/FreeRTOS.h"
#include "freertos/task.h"
#include "freertos/semphr.h"
#include "rom/ets_sys.h"
#include "esp_attr.h"
#include "esp_intr.h"
#include "rom/gpio.h"
#include "soc/spi_reg.h"
#include "soc/spi_struct.h"
#include "soc/io_mux_reg.h"
#include "soc/gpio_sig_map.h"
#include "soc/dport_reg.h"
#include "soc/rtc.h"

#define SPI_CLK_IDX(p)  ((p==0)?SPICLK_OUT_IDX:((p==1)?SPICLK_OUT_IDX:((p==2)?HSPICLK_OUT_IDX:((p==3)?VSPICLK_OUT_IDX:0))))
#define SPI_MISO_IDX(p) ((p==0)?SPIQ_OUT_IDX:((p==1)?SPIQ_OUT_IDX:((p==2)?HSPIQ_OUT_IDX:((p==3)?VSPIQ_OUT_IDX:0))))
#define SPI_MOSI_IDX(p) ((p==0)?SPID_IN_IDX:((p==1)?SPID_IN_IDX:((p==2)?HSPID_IN_IDX:((p==3)?VSPID_IN_IDX:0))))

#define SPI_SPI_SS_IDX(n)   ((n==0)?SPICS0_OUT_IDX:((n==1)?SPICS1_OUT_IDX:((n==2)?SPICS2_OUT_IDX:SPICS0_OUT_IDX)))
#define SPI_HSPI_SS_IDX(n)   ((n==0)?HSPICS0_OUT_IDX:((n==1)?HSPICS1_OUT_IDX:((n==2)?HSPICS2_OUT_IDX:HSPICS0_OUT_IDX)))
#define SPI_VSPI_SS_IDX(n)   ((n==0)?VSPICS0_OUT_IDX:((n==1)?VSPICS1_OUT_IDX:((n==2)?VSPICS2_OUT_IDX:VSPICS0_OUT_IDX)))
#define SPI_SS_IDX(p, n)   ((p==0)?SPI_SPI_SS_IDX(n):((p==1)?SPI_SPI_SS_IDX(n):((p==2)?SPI_HSPI_SS_IDX(n):((p==3)?SPI_VSPI_SS_IDX(n):0))))

#define SPI_INUM(u)        (2)
#define SPI_INTR_SOURCE(u) ((u==0)?ETS_SPI0_INTR_SOURCE:((u==1)?ETS_SPI1_INTR_SOURCE:((u==2)?ETS_SPI2_INTR_SOURCE:((p==3)?ETS_SPI3_INTR_SOURCE:0))))

struct spi_struct_t {
    spi_dev_t * dev;
#if !CONFIG_DISABLE_HAL_LOCKS
    xSemaphoreHandle lock;
#endif
    uint8_t num;
};

#if CONFIG_DISABLE_HAL_LOCKS
#define SPI_MUTEX_LOCK()
#define SPI_MUTEX_UNLOCK()

static spi_t _spi_bus_array[4] = {
    {(volatile spi_dev_t *)(DR_REG_SPI0_BASE), 0},
    {(volatile spi_dev_t *)(DR_REG_SPI1_BASE), 1},
    {(volatile spi_dev_t *)(DR_REG_SPI2_BASE), 2},
    {(volatile spi_dev_t *)(DR_REG_SPI3_BASE), 3}
};
#else
#define SPI_MUTEX_LOCK()    do {} while (xSemaphoreTake(spi->lock, portMAX_DELAY) != pdPASS)
#define SPI_MUTEX_UNLOCK()  xSemaphoreGive(spi->lock)

static spi_t _spi_bus_array[4] = {
    {(volatile spi_dev_t *)(DR_REG_SPI0_BASE), NULL, 0},
    {(volatile spi_dev_t *)(DR_REG_SPI1_BASE), NULL, 1},
    {(volatile spi_dev_t *)(DR_REG_SPI2_BASE), NULL, 2},
    {(volatile spi_dev_t *)(DR_REG_SPI3_BASE), NULL, 3}
};
#endif

void spiAttachSCK(spi_t * spi, int8_t sck)
{
    if(!spi) {
        return;
    }
    if(sck < 0) {
        if(spi->num == HSPI) {
            sck = 14;
        } else if(spi->num == VSPI) {
            sck = 18;
        } else {
            sck = 6;
        }
    }
    pinMode(sck, OUTPUT);
    pinMatrixOutAttach(sck, SPI_CLK_IDX(spi->num), false, false);
}

void spiAttachMISO(spi_t * spi, int8_t miso)
{
    if(!spi) {
        return;
    }
    if(miso < 0) {
        if(spi->num == HSPI) {
            miso = 12;
        } else if(spi->num == VSPI) {
            miso = 19;
        } else {
            miso = 7;
        }
    }
    //SPI_MUTEX_LOCK();
    pinMode(miso, INPUT);
    pinMatrixInAttach(miso, SPI_MISO_IDX(spi->num), false);
    //SPI_MUTEX_UNLOCK();
}

void spiAttachMOSI(spi_t * spi, int8_t mosi)
{
    if(!spi) {
        return;
    }
    if(mosi < 0) {
        if(spi->num == HSPI) {
            mosi = 13;
        } else if(spi->num == VSPI) {
            mosi = 23;
        } else {
            mosi = 8;
        }
    }
    pinMode(mosi, OUTPUT);
    pinMatrixOutAttach(mosi, SPI_MOSI_IDX(spi->num), false, false);
}

void spiDetachSCK(spi_t * spi, int8_t sck)
{
    if(!spi) {
        return;
    }
    if(sck < 0) {
        if(spi->num == HSPI) {
            sck = 14;
        } else if(spi->num == VSPI) {
            sck = 18;
        } else {
            sck = 6;
        }
    }
    pinMatrixOutDetach(sck, false, false);
    pinMode(sck, INPUT);
}

void spiDetachMISO(spi_t * spi, int8_t miso)
{
    if(!spi) {
        return;
    }
    if(miso < 0) {
        if(spi->num == HSPI) {
            miso = 12;
        } else if(spi->num == VSPI) {
            miso = 19;
        } else {
            miso = 7;
        }
    }
    pinMatrixInDetach(SPI_MISO_IDX(spi->num), false, false);
    pinMode(miso, INPUT);
}

void spiDetachMOSI(spi_t * spi, int8_t mosi)
{
    if(!spi) {
        return;
    }
    if(mosi < 0) {
        if(spi->num == HSPI) {
            mosi = 13;
        } else if(spi->num == VSPI) {
            mosi = 23;
        } else {
            mosi = 8;
        }
    }
    pinMatrixOutDetach(mosi, false, false);
    pinMode(mosi, INPUT);
}

void spiAttachSS(spi_t * spi, uint8_t cs_num, int8_t ss)
{
    if(!spi) {
        return;
    }
    if(cs_num > 2) {
        return;
    }
    if(ss < 0) {
        cs_num = 0;
        if(spi->num == HSPI) {
            ss = 15;
        } else if(spi->num == VSPI) {
            ss = 5;
        } else {
            ss = 11;
        }
    }
    pinMode(ss, OUTPUT);
    pinMatrixOutAttach(ss, SPI_SS_IDX(spi->num, cs_num), false, false);
    spiEnableSSPins(spi, (1 << cs_num));
}

void spiDetachSS(spi_t * spi, int8_t ss)
{
    if(!spi) {
        return;
    }
    if(ss < 0) {
        if(spi->num == HSPI) {
            ss = 15;
        } else if(spi->num == VSPI) {
            ss = 5;
        } else {
            ss = 11;
        }
    }
    pinMatrixOutDetach(ss, false, false);
    pinMode(ss, INPUT);
}

void spiEnableSSPins(spi_t * spi, uint8_t cs_mask)
{
    if(!spi) {
        return;
    }
    //SPI_MUTEX_LOCK();
    spi->dev->pin.val &= ~(cs_mask & SPI_CS_MASK_ALL);
    //SPI_MUTEX_UNLOCK();
}

void spiDisableSSPins(spi_t * spi, uint8_t cs_mask)
{
    if(!spi) {
        return;
    }
    //SPI_MUTEX_LOCK();
    spi->dev->pin.val |= (cs_mask & SPI_CS_MASK_ALL);
    //SPI_MUTEX_UNLOCK();
}

void spiSSEnable(spi_t * spi)
{
    if(!spi) {
        return;
    }
    //SPI_MUTEX_LOCK();
    spi->dev->user.cs_setup = 1;
    spi->dev->user.cs_hold = 1;
    //SPI_MUTEX_UNLOCK();
}

void spiSSDisable(spi_t * spi)
{
    if(!spi) {
        return;
    }
    //SPI_MUTEX_LOCK();
    spi->dev->user.cs_setup = 0;
    spi->dev->user.cs_hold = 0;
    //SPI_MUTEX_UNLOCK();
}

void spiSSSet(spi_t * spi)
{
    if(!spi) {
        return;
    }
    //SPI_MUTEX_LOCK();
    spi->dev->pin.cs_keep_active = 1;
    //SPI_MUTEX_UNLOCK();
}
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

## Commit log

2020-03-19 firmware for REV2 released
    Better performance (modified adafruit sharpmem library needed)
    Gyro Support and more "tech demo" apps
2020-03-19 REV2 release
    Added the MPU6050 and a shoulder button
    Battery cable connector moved to bottom
    [Memory Display V2.brd, Memory Display V2.sch]
2020-03-19 Added gifs of how the gyro can be utilized
2020-03-20 Added modified Adafruit SharpMem
    This library contains an improved function to fill the screen by writing to the display buffer directly.
    Also uses Hardware SPI (no major improvement over software sadly)

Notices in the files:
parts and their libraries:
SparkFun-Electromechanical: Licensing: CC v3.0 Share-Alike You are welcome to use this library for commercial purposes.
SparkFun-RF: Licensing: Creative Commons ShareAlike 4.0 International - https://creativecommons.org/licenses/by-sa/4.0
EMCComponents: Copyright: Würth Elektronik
